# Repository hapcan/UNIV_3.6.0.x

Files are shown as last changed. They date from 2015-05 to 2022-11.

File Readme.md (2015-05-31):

UNIV 3.6.0.x
============

Light Dimmer - 1 channel trailing edge light dimmer 250W for DIN rail

Device webpage: http://hapcan.com/devices/universal/univ_3/univ_3-6-0-x/

Hardware designed in Eagle PCB Software http://www.cadsoftusa.com/

Firmware created in Microchip MPLAB http://www.microchip.com/mplabide/ in assembly language

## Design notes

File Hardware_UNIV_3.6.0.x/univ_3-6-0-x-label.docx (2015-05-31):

DIMMER RC

| | UN = 230V AC 50Hz
| | PMAX = 250W
| | PMAX = 50W
TYPE | UNIV 3.6.0.x
S/N | 000007A6h

hapcan.com

ŚCIEMNIACZ RC

| | UN = 230V AC 50Hz
| | PMAX = 250W
| | PMAX = 50W
TYP | UNIV 3.6.0.x
S/N | 000007A6h

hapcan.com

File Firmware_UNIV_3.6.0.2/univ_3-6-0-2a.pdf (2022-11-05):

## DIMMER FIRMWARE

# UNIV 3.6.0.2

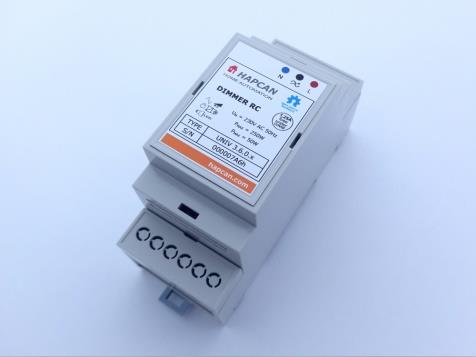
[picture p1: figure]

© 2019 hapcan.com | univ_3-6-0-2a.pdf - page 1 / 7

### 1. Features

- Firmware for light dimmer
- Voltage control in 256 steps (0-255)
- 4 defined dimmer characteristics
- Possibility to program user defined characteristic
- Adjustable minimum and maximum values
- Last state memory
- Adjustable dimming time for each channel
- 10 control instructions
- 3 blocking instructions
- 1 timer for instruction execution delay 1s-24h
- Allows defining up to 128 CAN messages which can indirectly control the module
- Settable power up states
- Uptime counter
- Health check monitor
- Transmit (42 messages) and receive (42 messages) FIFO buffers New:
- Operators <-small or equal and> greater than or equal were added to support boxes
- The flash of the light source that occurred when the set dimmer value was saved to the eeprom memory has been eliminated

### 2. Compatibility

- Firmware is compatible to previous UNIV 3.6.0.1
- Firmware for UNIV 3.6.0.x module
- Firmware can be uploaded into processor with bootloader version 3.1 or compatible.

### 3. Firmware version

UNIV | 3 | . | 6 | . | 0 | . | 2
firmware version
application version
application type (dimmer)
processor version
universal processor

### 4. Communication Frames (messages)

### 4.1. Dimmer message

The module sends message to the bus, when the dimmer state changes.

Table 1. Dimmer frame (0x306)
Frame type | Flags | Module | Group | D0 | D1 | D2 | D3 | D4 | D5 | D6 | D7
0x306 | 3 | 2 | 1 | 0 | Node Nr | Group Nr | 0xFF | 0xFF | CHANNEL | STATUS | 0xFF | INSTR1 | INSTR2 | TIMER
0x306 | – dimmer frame
3 | - | - not used flag, read as “0”
2 | - | - not used flag, read as “0”
1 | - | - not used flag, read as “0”
0 | RE | - response flag, flag is equal “1” if node was requested. If flag is equal „0” it means that status of output has just changed.
Node Nr | - message sender node number
Group Nr | - message sender group number
CHANNEL | - output channel (always 0x01 in this device)
STATUS | - current status of output 0x00 – 0xFF
INSTR1 | - instruction that is waiting for execution, or 0xFF if none instruction
INSTR2 | - second byte of instruction that is waiting for execution, or 0xFF
TIMER | - delay value of waiting instruction, or 0x00 if none waiting

Table 2. Dimmer error frame
The module sends message to the bus, when the dimmer error changes.
Frame type | Flags | Module | Group | D0 | D1 | D2 | D3 | D4 | D5 | D6 | D7
0x306 | 0x0 | Node Nr | Group Nr | 0xFF | 0xFF | 0xF0 | ERROR | 0xFF | 0xFF | 0xFF | 0xFF
0xF0 | - error frame
ERROR | 0x00 – <00000000> - no error 0x01 – <00000001> (bit 0) – 230V mains problem 0x02 – <00000010> (bit 1) - overheating

Table 3. Dimmer transistor conduction time
The frame is sent only in response to STATUS REQUEST
Frame type | Flags | Module | Group | D0 | D1 | D2 | D3 | D4 | D5 | D6 | D7
0x306 | 0x1 | Node Nr | Group Nr | 0xFF | 0xFF | 0xFE | COND1 | COND0 | 0xFF | 0xFF | 0xFF
0xFE | MOSFET - transistor conduction time frame
COND | - COND1*256 + COND0 – transistor conduction time frame in mains half sine wave (in microseconds)

Table 4. Mains frequency frame
The frame is sent only in response to STATUS REQUEST
Frame type | Flags | Module | Group | D0 | D1 | D2 | D3 | D4 | D5 | D6 | D7
0x306 | 0x1 | Node Nr | Group Nr | 0xFF | 0xFF | 0xFF | FREQ1 | FREQ0 | 0xFF | 0xFF | 0xFF
0xFF | - mains frequency frame
FREQ | - FREQ1*256 + FREQ0 – mains sine wave half period time (value in microseconds)

### 4.2. Status request

Status of module can be checked by sending from computer STATUS REQUEST frame (0x109) (Table 5).

Table 5. STATUS REQUEST frame (0x109).
Frame type | Flags | Module | Group | D0 | D1 | D2 | D3 | D4 | D5 | D6 | D7
0x109 | 0x0 | COMP ID1 | COMP ID2 | 0xXX | 0xXX | Node Nr | Group Nr | 0xXX | 0xXX | 0xXX | 0xXX
0x1090 | – STATUS REQUEST frame
COMP ID1 | - computer identifier (must be unique on the network)
COMP ID2 | - computer identifier (must be unique on the network)
Node Nr | - node number of requested module
Group Nr | - group number of requested module
0xXX | - inessential data

As response the module will send dimmer frames. The meaning of bytes is the same as in Table 1,2,3,4.

Table 6. Response to STATUS REQUEST
Frame type | Flags | Module | Group | D0 | D1 | D2 | D3 | D4 | D5 | D6 | D7
0x306 | 0x1 | Node Nr | Group Nr | 0xFF | 0xFF | CHANNEL | STATUS | 0xFF | INSTR1 | INSTR2 | TIMER
Frame type | Flags | Module | Group | D0 | D1 | D2 | D3 | D4 | D5 | D6 | D7
0x306 | 0x1 | Node Nr | Group Nr | 0xFF | 0xFF | 0xF0 | ERROR | 0xFF | 0xFF | 0xFF | 0xFF
Frame type | Flags | Module | Group | D0 | D1 | D2 | D3 | D4 | D5 | D6 | D7
0x306 | 0x1 | Node Nr | Group Nr | 0xFF | 0xFF | 0xFE | COND1 | COND0 | 0xFF | 0xFF | 0xFF
Frame type | Flags | Module | Group | D0 | D1 | D2 | D3 | D4 | D5 | D6 | D7
0x306 | 0x1 | Node Nr | Group Nr | 0xFF | 0xFF | 0xFF | FREQ1 | FREQ0 | 0xFF | 0xFF | 0xFF

### 4.3. Uptime request

Table 7. UPTIME REQUEST (0x113).
Frame type | Flags | Module | Group | D0 | D1 | D2 | D3 | D4 | D5 | D6 | D7
0x113 | 0x0 | COMP ID1 | COMP ID2 | 0xXX | 0xXX | Node Nr | Group Nr | 0xXX | 0xXX | 0xXX | 0xXX
0x1130 | – UPTIME REQUEST frame
COMP ID1 | - computer identifier (must be unique on the network)
COMP ID2 | - computer identifier (must be unique on the network)
Node Nr | - node number of requested module
Group Nr | - group number of requested module
0xXX | - inessential data

Table 8. Response to UPTIME REQUEST (0x113).
Frame type | Flags | Module | Group | D0 | D1 | D2 | D3 | D4 | D5 | D6 | D7
0x113 | 0x1 | Node Nr | Group Nr | 0xFF | 0xFF | 0xFF | 0xFF | UPTIME3 | UPTIME2 | UPTIME1 | UPTIME0
0x1131 | – Response to UPTIME REQUEST frame
Node Nr | - node number on the network
Group Nr | - group number of the node on the network
UPTIME | - (UPTIME3*256³+UPTIME2*256²+UPTIME1*256¹+UPTIME3*256⁰
) in seconds

### 4.4. Health check request

Table 9. HEALTH CHECK - STATUS REQUEST (0x115).
Frame type | Flags | Module | Group | D0 | D1 | D2 | D3 | D4 | D5 | D6 | D7
0x115 | 0x0 | COMP ID1 | COMP ID2 | 0x01 | 0xXX | Node Nr | Group Nr | 0xXX | 0xXX | 0xXX | 0xXX
0x1150 | – HEALTH CHECK REQUEST frame
COMP ID1 | - computer identifier (must be unique on the network)
COMP ID2 | - computer identifier (must be unique on the network)
0x01 | - status request
Node Nr | - node number of requested module
Group Nr | - group number of requested module
0xXX | - inessential data

As response the module will send two frames (Table 10).

Table 10. Response to HEALTH CHECK - STATUS REQUEST (0x115).
Frame type | Flags | Module | Group | D0 | D1 | D2 | D3 | D4 | D5 | D6 | D7
0x115 | 0x1 | Node Nr | Group Nr | 0x01 | RXCNT | TXCNT | RXCNTMX | TXCNTMX | CANINTCNT | RXERRCNT | TXERRCNT
0x1151 | – Response to HEALTH CHECK REQUEST frame
Node Nr | - node number on the network
Group Nr | - group number of the node on the network
0x01 | - frame 1 (current values)
RXCNT | - current level of receive FIFO buffer
TXCNT | - current level of transmit FIFO buffer
RXCNTMX | - maximum level of receive FIFO buffer since power up
TXCNTMX | - maximum level of transmit FIFO buffer since power up
CANINTCNT | - number of CAN interface restarts since power up
RXERRCNT | - current receive errors register
TXERRCNT | - current transmit errors register
Frame type | Flags | Module | Group | D0 | D1 | D2 | D3 | D4 | D5 | D6 | D7
0x115 | 0x1 | Node Nr | Group Nr | 0x02 | 0xFF | 0xFF | RXCNTMXE | TXCNTMXE | CANINTCNTE | RXERRCNTE | TXERRCNTE
0x1151 | – Response to HEALTH CHECK REQUEST frame
Node Nr | - node number on the network
Group Nr | - group number of the node on the network
0x02 | - frame 2 (maximum values saved in eeprom memory)
RXCNTMXE | - maximum ever level of receive FIFO buffer
TXCNTMXE | - maximum ever level of transmit FIFO buffer
CANINTCNTE | - maximum ever number of CAN interface restarts
RXERRCNTE | - maximum ever receive errors
TXERRCNTE | - maximum ever transmit errors

To clear maximum values saved in eeprom memory the frame shown in Table 11 must be sent. There is no response to this message.

Table 11. HEALTH CHECK - CLEAR REQUEST (0x115).
Frame type | Flags | Module | Group | D0 | D1 | D2 | D3 | D4 | D5 | D6 | D7
0x115 | 0x0 | COMP ID1 | COMP ID2 | 0x02 | 0xXX | Node Nr | Group Nr | 0xXX | 0xXX | 0xXX | 0xXX
0x1150 | – HEALTH CHECK REQUEST frame
COMP ID1 | - computer identifier (must be unique on the network)
COMP ID2 | - computer identifier (must be unique on the network)
0x02 | - clear request
Node Nr | - node number of requested module
Group Nr | - group number of requested module
0xXX | - inessential data

### 5. Module control

The module can be controlled directly from PC, or indirectly by other modules.

### 5.1. Control instruction

The table below shows all instructions, which can be executed by the module. Some of them can be executed only with direct control and other with indirect control (through other modules).

Table 12. Module control instructions

Instruction | Instruction Codding | Note | Control
INSTR1 | INSTR2 | INSTR3 | INSTR4 | INSTR5 | INSTR6 | INSTR7 | INSTR8
SET TO… | 0x00 | STATE | TIMER | 0xXX | 0xXX | 0xXX | 0xXX | 0xXX | Sets the state of the dimmer immediately at the level specified by the byte STATE (0-255). The SOFT START feature takes 1s to turn device on and off. Instructions may be delayed if the TIMER is not zero. | √ | √
TOGGLE | 0x01 | 0xXX | TIMER | 0xXX | 0xXX | 0xXX | 0xXX | 0xXX | If dimmer is on, it will be turned off. If it is off, it will be turned to the maximum or the last memorized value (if state memory is set in the configuration). Instructions may be delayed if the TIMER is not zero. | √ | √
STEP DOWN BY … | 0x02 | VALUE | TIMER | 0xXX | 0xXX | 0xXX | 0xXX | 0xXX | Dimmer state will be reduced by the value indicated in the VALUE byte. | √ | √
STEP UP BY … | 0x03 | VALUE | TIMER | 0xXX | 0xXX | 0xXX | 0xXX | 0xXX | Dimmer state will be increased by the value indicated in the VALUE byte. | √ | √
STOP | 0x04 | 0xXX | 0xXX | 0xXX | 0xXX | 0xXX | 0xXX | 0xXX | It stops instruction which is being executed eg. START or SET SOFTLY TO ... | √ | √
START | 0x05 | 0xXX | 0xXX | 0xXX | 0xXX | 0xXX | 0xXX | 0xXX | Instruction START begins typical control process. If within 400ms from START instruction, controller receives STOP instruction then it toggles channel’s state (exactly the same as TOGGLE instruction). If after that time instruction STOP is not received then dimmer is brightened (if previous state was min or 0), or channel is dimmed (if previous state was max). It gives possibility to control with one button. If button is pressed for less than 400ms the dimmer will turn on or off. If button is pressed for longer than 400ms, then dimmer will dim or brighten. | √ | √
SET SOFTLY TO… | 0x06 | STATE | TIMER | 0xXX | 0xXX | 0xXX | 0xXX | 0xXX | Sets the dimmer statel slowly to the level specified by the byte STATE (0-255). Instructions may be delayed if the TIMER is not zero. | √ | √
SET MINIMUM TO… | 0x07 | VALUE | 0xXX | 0xXX | 0xXX | 0xXX | 0xXX | 0xXX | Sets dimmer minimum value. Byte VALUE (0-255). | √ | √
SET MAXIMUM TO … | 0x08 | VALUE | 0xXX | 0xXX | 0xXX | 0xXX | 0xXX | 0xXX | Sets dimmer maximum value. Byte VALUE (0-255). | √ | √
SET DIMMING SPEED TO … | 0x09 | VALUE | 0xXX | 0xXX | 0xXX | 0xXX | 0xXX | 0xXX | It sets dimming time. VALUE byte (0-255) defines time when dimmer changes its state from 0 to 255. This byte can hold value from 0 – 255 which corresponds to 1s – 256s. | √ | √
ENABLE BOX | 0xDD | BoxX | BoxY | 0xXX | 0xXX | 0xXX | 0xXX | 0xXX | It enables chosen boxes – these boxes will be compared with next received message from the bus. | | √
DISABLE BOX | 0xDE | BoxX | BoxY | 0xXX | 0xXX | 0xXX | 0xXX | 0xXX | It disables chosen boxes – these boxes will be passed when next message arrives from the bus. | | √
TOGGLE BOX | 0xDF | BoxX | BoxY | 0xXX | 0xXX | 0xXX | 0xXX | 0xXX | It toggles boxes – enables when they are disabled and vice versa | | √

Direct

Indirect

0xXX – inessential data

BoxX | Note
0x00 | - from Box 1
0x01 | - from Box 2
…
0x7F | - from Box 128
BoxY | Note
0x00 | + 0 -(and not anyone else)
0x01 | + 1 -( and 1 following)
…
0x7F | +127 -( and 127 following)

### 5.2. Timer

Each channel has its own timer which can delay execution of the instruction. Delay can be chosen between 1s-24h set in TIMER register. Drawing below shows delay dependence of TIMER register.

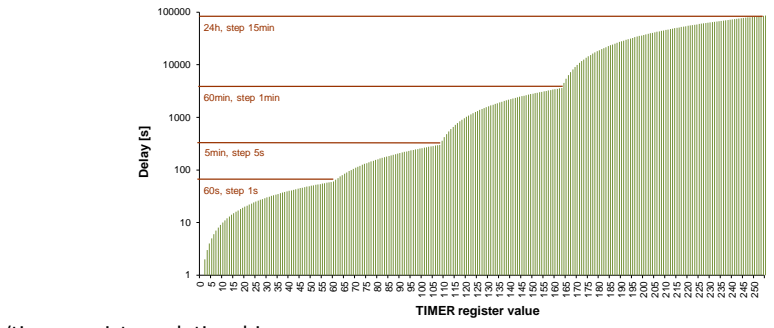
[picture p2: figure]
Delay [s]; TIMER register value; 60s, step 1s; 5min, step 5s; 60min, step 1min; 24h, step 15min

Figure 1. Delay/timer register relationship

### 5.3. Direct control

It is possible to control module by sending DIRECT CONTROL message. The message contains instruction, which will be executed by the module.

Table 13. DIRECT CONTROL frame (0x10A).
Frame type | Flags | Module | Group | D0 | D1 | D2 | D3 | D4 | D5 | D6 | D7
0x10A | 0x0 | COMP ID1 | COMP ID2 | INSTR1 | INSTR2 | Node Nr | Group Nr | INSTR3 | INSTR4 | INSTR5 | INSTR6
0x10A | – DIRECT CONTROL frame
COMP ID1 | - computer identifier (must be unique on the network)
COMP ID2 | - computer identifier (must be unique on the network)
Node Nr | - node number of requested module
Group Nr | - group number of requested module
INSTR1-6 | - instruction to be executed (byte1)

### 5.4. Indirect control

Indirect control means that module will react to messages sent by other modules on the network. It depends on configuration programmed into the module boxes (memory cells).
This firmware has feature to set simple conditions of executing instruction. To do so, you can use blocking instruction (0xDD – 0xDF) shown in Table 12.

### 6. Configuration

Parameters that can be configured with this firmware. Configuration process can be made using HAPCAN Programmer.

### 6.1. Module identifier

Every module on the network must have unique identifier. The identifier is made of two bytes, module number (1 byte) and group number (1 byte).

### 6.2. Module description

Every module can have 16 char description, which makes easier for user (programmer) to distinguish nodes.

### 6.3. Dimmer channel name

The only one channel of this device can be named with 32 chars.

### 6.4. Power up minimum and maximum values

It is possible to set minimum and maximum values.

### 6.5. Power up dimming speed

This parameter defines how fast dimmer goes from value 0 to value 255. The dimming speed can be chosen between 1s and 256s with 1s step.

### 6.6. Power up state

It is possible to configure dimmer state at startup after power loss. At startup values can be chosen between 0 and 255 or the or the last state saved in non-volatile memory can be taken. The last state value must be unchanged for at least 6s before power failure.

### 6.7. Last state memory

The dimmer last state can be remembered. In this mode, when channel is being switched on, it sets to the value that was before switching off. In no state memory mode it sets to the maximum value.

### 6.8. Dimmer characteristics

One of five dimmer characteristics can be chosen. For the light control is it advised to choose square or incandescent curve. Only few types of LED bulbs might require “LED” curve.

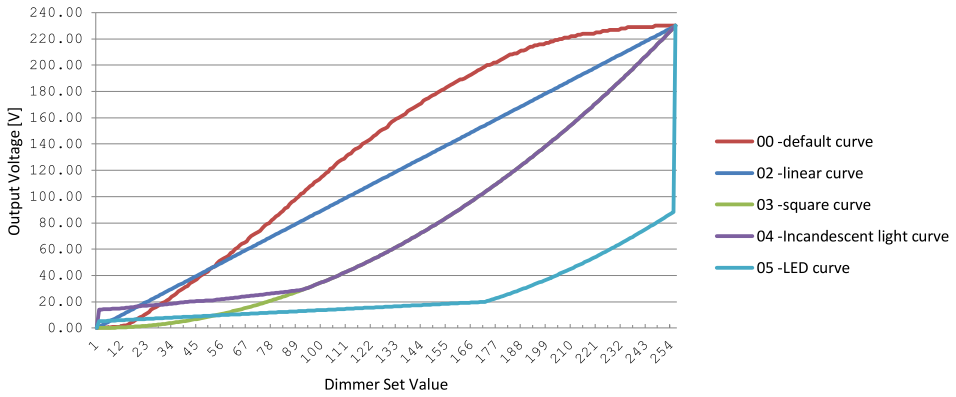
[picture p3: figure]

Figure 2. Defined dimmer characteristics.

### 6.9. User defined characteristic

When defining user characteristic it is required to set, for each dimmer value, the transistor conduction time in the half period of mains sine wave. This time must be contained within the range 0 - 9215 µs. Value equal or greater than 9215 µs means a continuous conduction of the transistor.

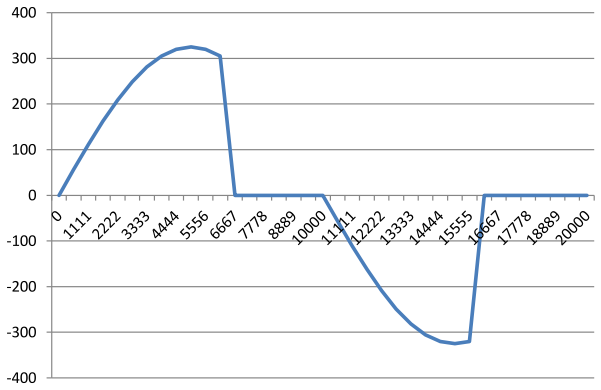
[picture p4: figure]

Figure 3. An example of the transistor conduction time equal 6667µs

6.10. Text notes.
Up to 1024 characters can be written into processor’s memory.

### 6.11. Linking devices

The indirect control is used to program the dependencies between modules. It is a controlling the module by messages sent from other modules. Each module when changing its status (eg when button is pressed or released in the button module) sends information that can be used to control the same module, as well as to control other modules located on the bus. For this purpose, the module has 128 boxes (memory cells) into which you can enter messages to which the module is to react when it receives them from the bus. Each box contains information about what message should initiate the action and what instruction should be made when this message is received.

In the figure on a side, the toggle instruction has been programmed, which changes the current state of the dimmer at the moment of receiving a message from the module button o ID (4.1) - see the description of the BUTTON FRAME in the document "Firmware note" of the button module.

The message bytes are saved in hexadecimal format.

Operators at the front of bytes indicate that the module will react to a message received from the bus in which this byte:
x - can have any value
= - is identical to byte entered here
! - is different than byte entered here
< - is less or equal to byte entered here
> - is greater or equal to byte entered here

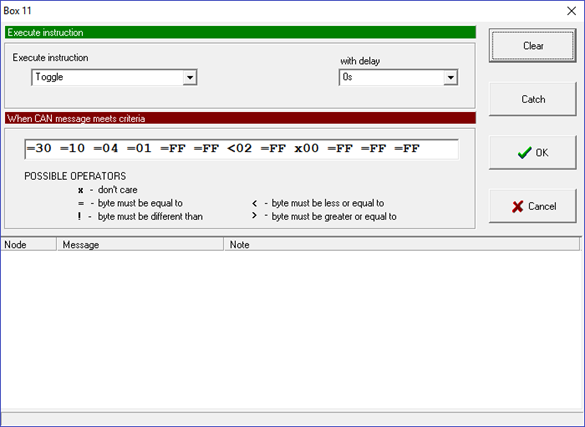
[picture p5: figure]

In this example:
=30 =10
=04 =01
=FF =FF
<02
=FF
x00

=FF =FF =FF

– button message
– module ID is (4,1)
– these bytes are not used and in button frame are always 0xFF
– button number is less or equal 2, means button number 1 or 2
– button is pressed
– it is a byte which gives LED status in the button module. Because we don’t want to make instruction execution to be depended on this byte, so this byte can have any value.
– these bytes are not used and in button frame are always 0xFF

As a result, the module will execute instructions when the module receives a message from the button with ID (4.1), when button number 1 or 2 has been pressed. Instruction is executed regardless of the LED status in the button module.

Each own and received from the bus message informing about the change of module status is checked with each active (enabled) box in the order from box no. 1 to 128. Therefore, you can set the reaction to the same message in two or more boxes. For example, in the first box instruction can be executed without delay, and in the next box another instruction can be executed after the defined time. It is important to keep the logical order of instruction executing to get the desired operation of the module. Calling an instruction that is to be executed without delay will cancel the previously set instruction with a delay.
Boxes can be dynamically activated (enabled) and deactivated (disabled). Blocking instructions 0xDD-0XDF are used for this (Table 12). In this way, you can control which boxes are to be checked after receiving the message.

### 7. License

HAPCAN Home Automation Project firmware, Copyright (C) 2019 hapcan.com

This program is free firmware: you can redistribute it and/or modify it under the terms of the GNU General Public License as published by the Free Software Foundation, either version 3 of the License, or (at your option) any later version.

This firmware is distributed in the hope that it will be useful, but WITHOUT ANY WARRANTY; without even the implied warranty of MERCHANTABILITY or FITNESS FOR A PARTICULAR PURPOSE. See the GNU General Public License for more details.

You should have received a copy of the GNU General Public License along with this firmware. If not, see http://www.gnu.org/licenses/gpl-3.0.html.

### 8. Document version

File | Note | Date
univ_3-6-0-2a.pdf | Original version | February 2019

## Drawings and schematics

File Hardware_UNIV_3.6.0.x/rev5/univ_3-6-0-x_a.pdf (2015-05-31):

## DIMMER RC

# UNIV 3.6.0.x

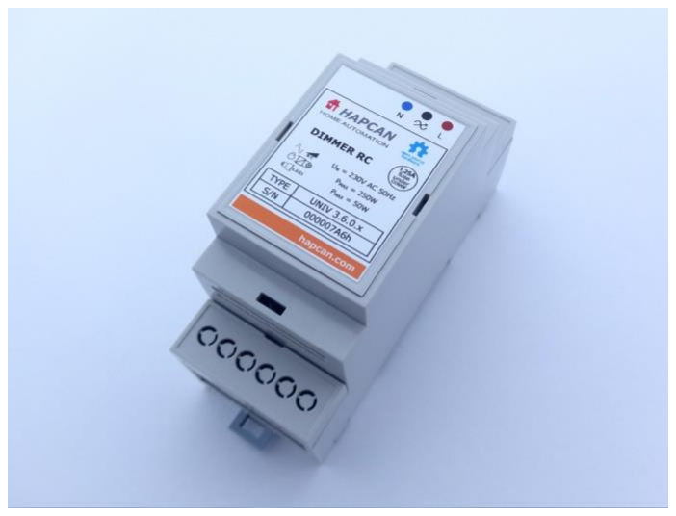
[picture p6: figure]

© 2015 hapcan.com | univ_3-6-0-x_a.pdf - page 1 / 6

### 1. Features

- Light dimmer for maximum load 250W
- - Phase controlled (trailing edge)
- - Suitable for resistive and capacitive loads:
- incandescent lamps (classic and halogen 230V) – maximum load 250W
- dimmable electronic transformers – maximum load 250W
- dimmable LED 230V lamps – maximum load 50W
- It has electronic thermal protection
- Blow fuse for overload and short-circuit protection
- Operation voltage 10-24V.
- Maximum current consumption from the bus 8mA.
- For DIN rail mounting.
- Dimensions 90x58x36 mm (2 mod)
- Operating of module depends on firmware uploaded into it.
- Schematic and PCB design can be downloaded from hapcan.com site

WARNING. MAINS VOLTAGES ARE ACCESSIBLE WHEN THE COVER IS REMOVED. ENSURE ANY EXTERNAL WIRING IS CARRIED OUT SAFELY. IN ANY DOUBT CONSULT A SUITABLY QUALIFIED PERSON. PLEASE TAKE CARE WITH MAINS ELECTRICITY.

### 2. Application version

UNIV | 3 | . | 6 | . | 0 | . | x
firmware version
application version
application type (dimmer)
processor version
universal processor

### 3. Technical data

Bus side
Parameter | Symbol | Value | Unit
Power supply voltage | US | 10-24V | V
Maximum current consumption | ISMAX | 8 | mA
Bus connector type | 2x RJ45 connectors

Load side
Parameter | Symbol | Value | Unit
Power supply voltage | UN | 230 | V AC
Power supply frequency | fN | 50 | Hz

Maximum load
Classical and halogen 230V lamps, low voltage lamps with electronic transformer | PLOAD | 250 | W
LED 230V lamps | | 50
Voltage regulating range | Uφ | 0 – UN | V
Standby power consumption | P0 | <1 | W
Quick acting fuse 5x20mm | | 1.25 | A
Connector type | Terminal block (solid cable 4mm² , stranded 2,5mm² )

R C

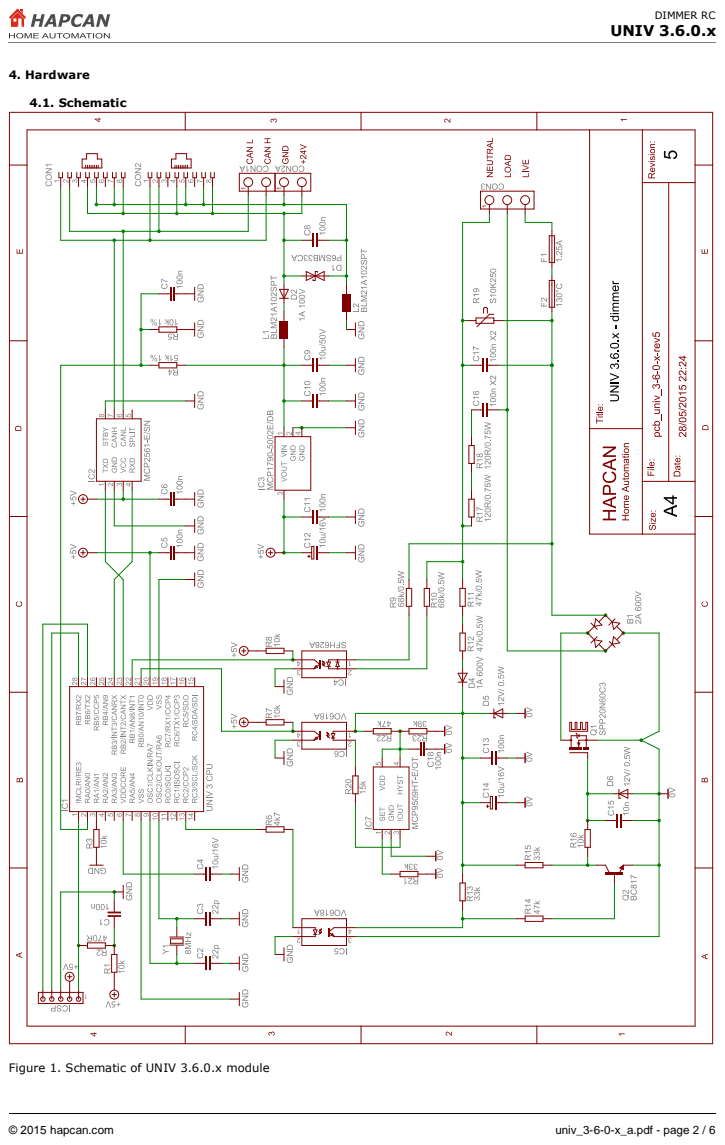
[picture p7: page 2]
4. Hardware; 4.1. Schematic

Figure 1. Schematic of UNIV 3.6.0.x module

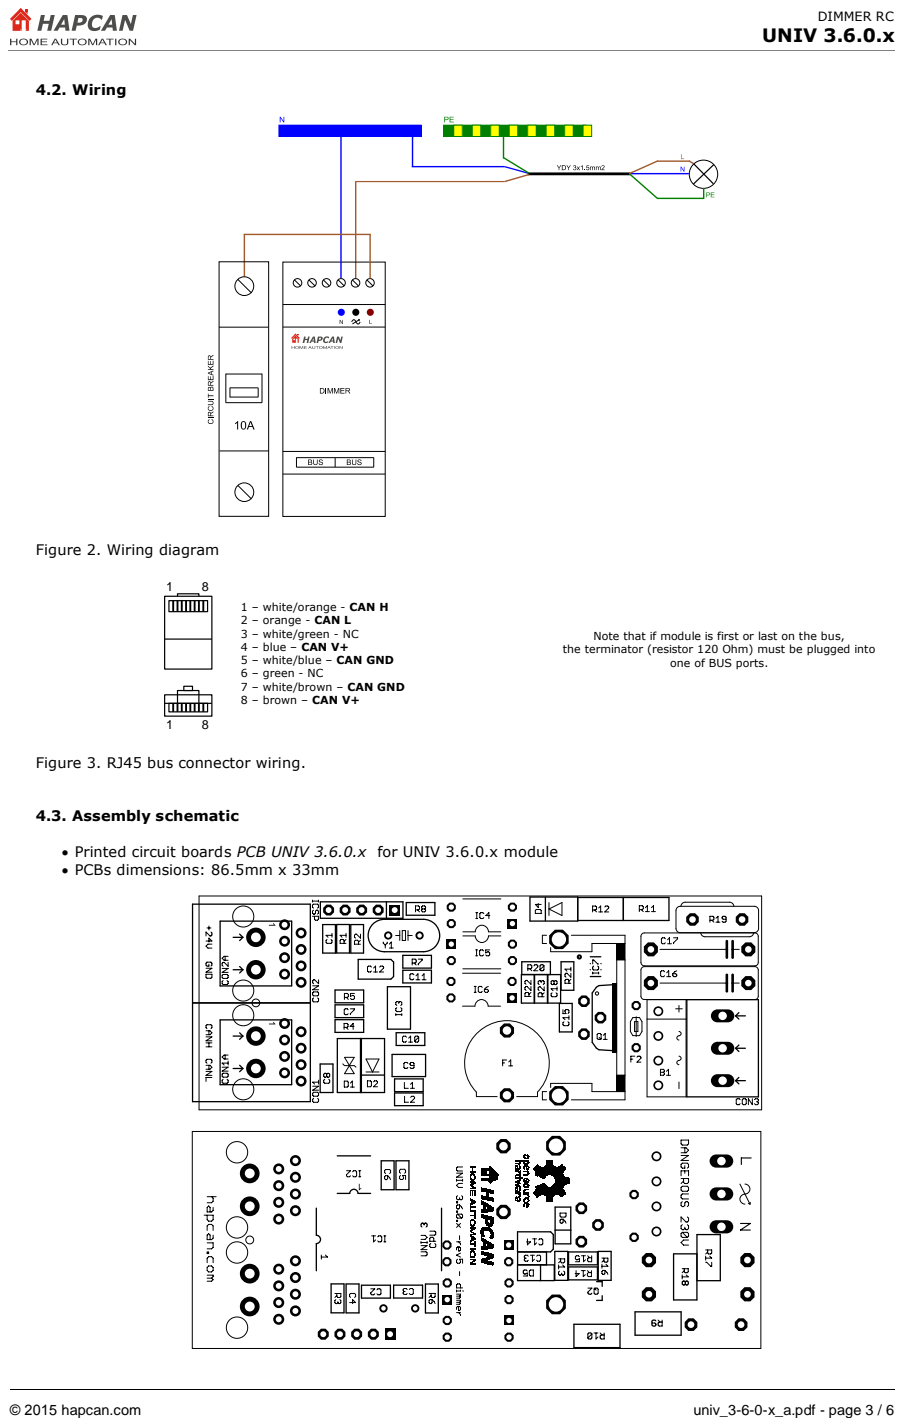
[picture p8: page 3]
4.2. Wiring; 4.3. Assembly schematic

Figure 2. Wiring diagram

1 – white/orange - CAN H
2 – orange - CAN L
3 – white/green - NC
4 – blue – CAN V+
5 – white/blue – CAN GND
6 – green - NC
7 – white/brown – CAN GND
8 – brown – CAN V+

Note that if module is first or last on the bus,
the terminator (resistor 120 Ohm) must be plugged into

one of BUS ports.

Figure 3. RJ45 bus connector wiring.

• Printed circuit boards PCB UNIV 3.6.0.x for UNIV 3.6.0.x module
• PCBs dimensions: 86.5mm x 33mm

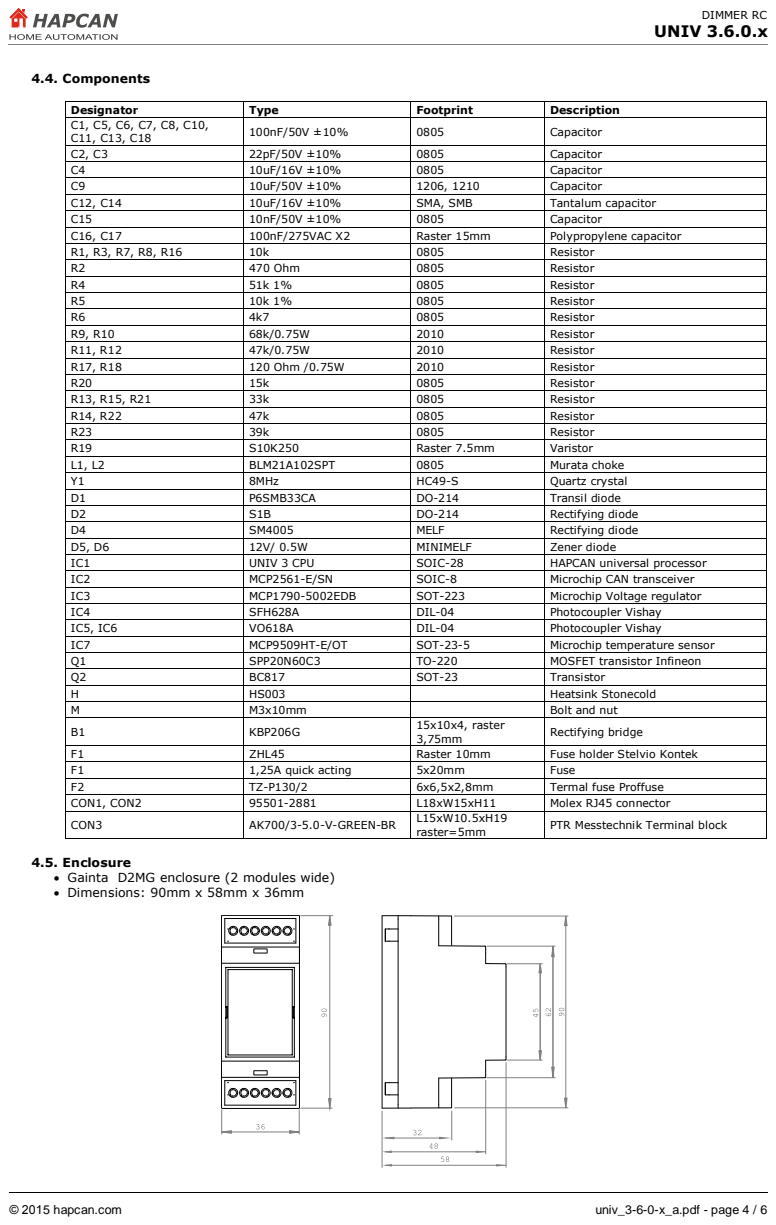
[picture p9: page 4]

Designator | Type | Footprint | Description
C1, C5, C6, C7, C8, C10, C11, C13, C18 | 100nF/50V ±10% | 0805 | Capacitor

C2, C3 | 22pF/50V ±10% | 0805 | Capacitor
C4 | 10uF/16V ±10% | 0805 | Capacitor
C9 | 10uF/50V ±10% | 1206, 1210 | Capacitor
C12, C14 | 10uF/16V ±10% | SMA, SMB | Tantalum capacitor
C15 | 10nF/50V ±10% | 0805 | Capacitor
C16, C17 | 100nF/275VAC X2 | Raster 15mm | Polypropylene capacitor
R1, R3, R7, R8, R16 | 10k | 0805 | Resistor
R2 | 470 Ohm | 0805 | Resistor
R4 | 51k 1% | 0805 | Resistor
R5 | 10k 1% | 0805 | Resistor
R6 | 4k7 | 0805 | Resistor
R9, R10 | 68k/0.75W | 2010 | Resistor
R11, R12 | 47k/0.75W | 2010 | Resistor
R17, R18 | 120 Ohm /0.75W | 2010 | Resistor
R20 | 15k | 0805 | Resistor
R13, R15, R21 | 33k | 0805 | Resistor
R14, R22 | 47k | 0805 | Resistor
R23 | 39k | 0805 | Resistor
R19 | S10K250 | Raster 7.5mm | Varistor
L1, L2 | BLM21A102SPT | 0805 | Murata choke
Y1 | 8MHz | HC49-S | Quartz crystal
D1 | P6SMB33CA | DO-214 | Transil diode
D2 | S1B | DO-214 | Rectifying diode
D4 | SM4005 | MELF | Rectifying diode
D5, D6 | 12V/ 0.5W | MINIMELF | Zener diode
IC1 | UNIV 3 CPU | SOIC-28 | HAPCAN universal processor
IC2 | MCP2561-E/SN | SOIC-8 | Microchip CAN transceiver
IC3 | MCP1790-5002EDB | SOT-223 | Microchip Voltage regulator
IC4 | SFH628A | DIL-04 | Photocoupler Vishay
IC5, IC6 | VO618A | DIL-04 | Photocoupler Vishay
IC7 | MCP9509HT-E/OT | SOT-23-5 | Microchip temperature sensor
Q1 | SPP20N60C3 | TO-220 | MOSFET transistor Infineon
Q2 | BC817 | SOT-23 | Transistor
H | HS003 | | Heatsink Stonecold
M | M3x10mm | | Bolt and nut
B1 | KBP206G | 15x10x4, raster 3,75mm | Rectifying bridge

F1 | ZHL45 | Raster 10mm | Fuse holder Stelvio Kontek
F1 | 1,25A quick acting | 5x20mm | Fuse
F2 | TZ-P130/2 | 6x6,5x2,8mm | Termal fuse Proffuse
CON1, CON2 | 95501-2881 | L18xW15xH11 | Molex RJ45 connector
CON3 | AK700/3-5.0-V-GREEN-BR | L15xW10.5xH19 raster=5mm | PTR Messtechnik Terminal block

4.5. Enclosure
• Gainta D2MG enclosure (2 modules wide)
• Dimensions: 90mm x 58mm x 36mm
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

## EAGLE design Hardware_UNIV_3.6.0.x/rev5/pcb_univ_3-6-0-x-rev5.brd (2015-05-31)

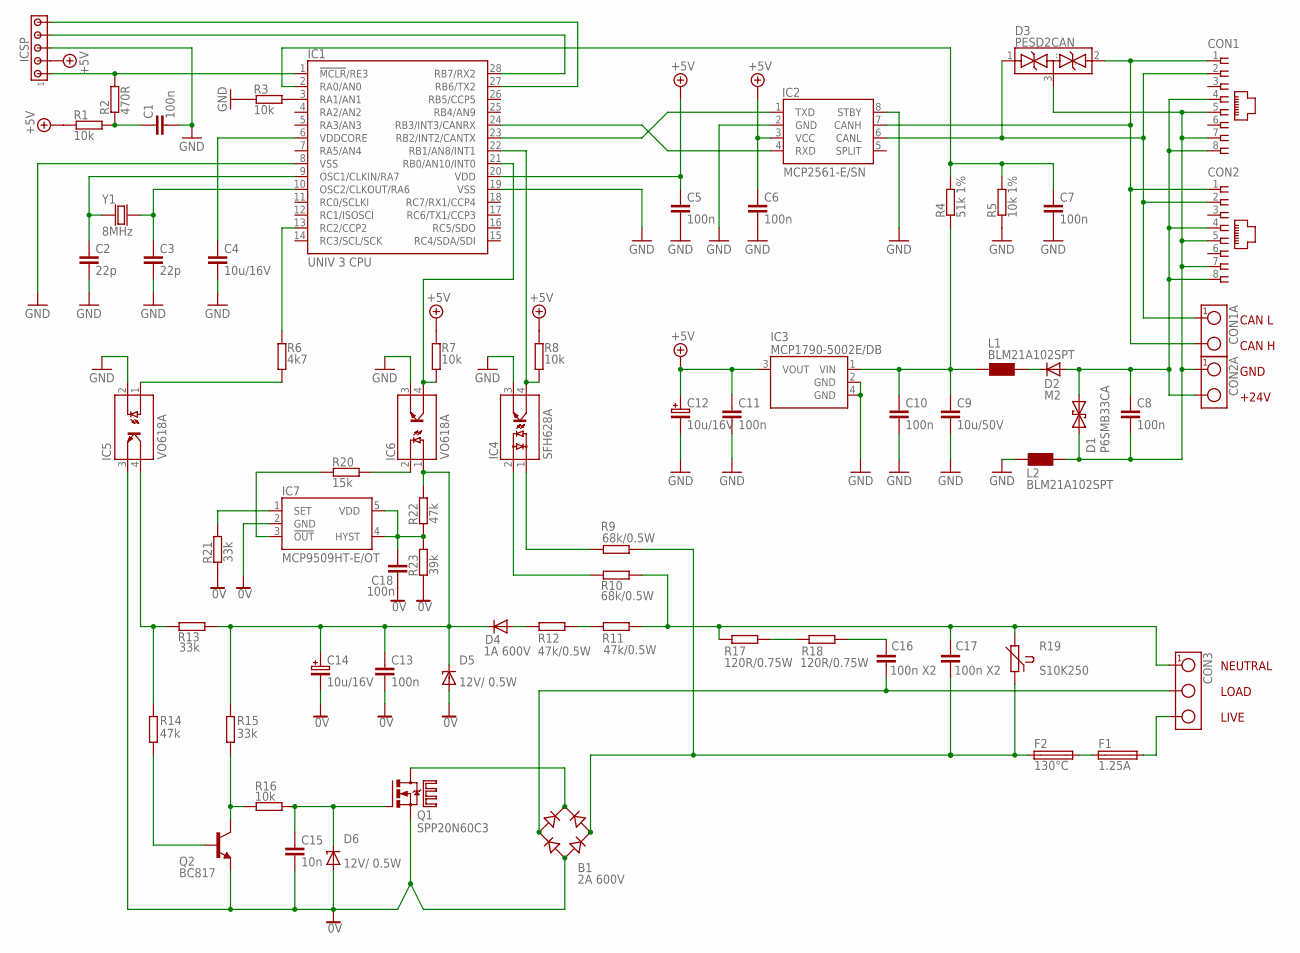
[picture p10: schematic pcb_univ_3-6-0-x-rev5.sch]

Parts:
B1: 2A 600V; RECTIFIER_KBP
C1, C5, C6, C7, C8, C10, C11, C13, C18: 100n; 0805
C2, C3: 22p; 0805
C4: 10u/16V; 0805
C9: 10u/50V; 1210
C12, C14: 10u/16V; SMC_B
C15: 10n; 0805
C16, C17: 100n X2; CAP-15X5
CON1, CON2: RJ45-SOCKET; RJ45-PCB-SOCKET
CON1A, CON2A: TERMINAL-2; ARK2-5X10,5MM
CON3: TERMINAL-3; ARK3-5X10.5MM
D1: P6SMB33CA; DO-214_TRANSIL2
D2: M2; DO-214
D3: PESD2CAN; SOT-23
D4: 1A 600V; DO-213
D5, D6: 12V/ 0.5W; SOD-80
F1: 1.25A; FUSE-HOLDER-V
F2: 130°C; FUSE-7.5
IC1: UNIV 3 CPU; UNIV3CPU
IC2: MCP2561-E/SN; SO-08
IC3: MCP1790-5002E/DB; SOT-223
IC4: SFH628A; DIL-04W
IC5, IC6: VO618A; DIL-04W
IC7: MCP9509HT-E/OT; SOT-23-5
ICSP: HEADER5; SIP-5
L1, L2: BLM21A102SPT; 0805
Q1: SPP20N60C3; TO220V-3
Q2: BC817; SOT-23
R1, R3, R7, R8, R16: 10k; 0805
R2: 470R; 0805
R4: 51k 1%; 0805
R5: 10k 1%; 0805
R6: 4k7; 0805
R9, R10: 68k/0.5W; 2010
R11, R12: 47k/0.5W; 2010
R13, R15, R21: 33k; 0805
R14, R22: 47k; 0805
R17, R18: 120R/0.75W; 2010
R19: S10K250; VARISTOR3
R20: 15k; 0805
R23: 39k; 0805
U$1: HEATSINK_HS003; HEATSINK_HS-003
Y1: 8MHz; CRYSTAL-HC49V

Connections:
0V: B1.-, C13.2, C14.- (2), C15.2, C18.2, D5.A, D6.A, IC5.3 (E), IC7.2 (GND), Q1.3 (S), Q2.2 (E), R21.2, R23.2
+5V: C5.1, C6.1, C11.1, C12.+ (1), IC1.20 (VDD), IC2.3 (VCC), IC3.3 (VOUT), ICSP.2, R1.1, R7.2, R8.2
GND: C1.2, C2.2, C3.2, C4.2, C5.2, C6.2, C7.2, C9.2, C10.2, C11.2, C12.- (2), IC1.8 (VSS), IC1.19 (VSS), IC2.2 (GND), IC2.8 (STBY), IC3.2 (GND), IC3.4 (GND), IC4.3 (E1), IC5.2 (K), IC6.3 (E), ICSP.3, L2.1, R3.1, R5.1
unnamed: C13.1, C14.+ (1), D4.C, D5.C, IC6.1 (A), R13.2, R15.1, R22.2
unnamed: IC1.24 (RB3/INT3/CANRX), IC2.4 (RXD)
unnamed: IC1.23 (RB2/INT2/CANTX), IC2.1 (TXD)
unnamed: CON1.1, CON1A.2, CON2.1, D3.2 (..), IC2.7 (CANH)
unnamed: IC4.2 (A2), R10.1
unnamed: B1.+, Q1.2 (D)
unnamed: C1.1, R1.2, R2.1
unnamed: IC1.1 (!MCLR!/RE3), ICSP.1, R2.2
unnamed: C8.1, CON1.4, CON1.8, CON2.4, CON2.8, CON2A.2, D1.C (2), D2.A
unnamed: IC1.28 (RB7/RX2), ICSP.4
unnamed: Q2.3 (C), R15.2, R16.2
unnamed: IC1.3 (RA1/AN1), R3.2
unnamed: B1.AC2, C17.2, F2.1, R9.2, R19.1
unnamed: IC1.27 (RB6/TX2), ICSP.5
unnamed: C3.1, IC1.10 (OSC2/CLKOUT/RA6), Y1.2
unnamed: C7.1, IC1.2 (RA0/AN0), R4.2, R5.2
unnamed: C9.1, C10.1, IC3.1 (VIN), L1.1, R4.1
unnamed: C15.1, D6.C, Q1.1 (G), R16.1
unnamed: IC1.13 (RC2/CCP2), R6.1
unnamed: B1.AC1, C16.1, CON3.2
unnamed: R11.2, R12.1
unnamed: CON3.3, F1.1
unnamed: IC4.1 (A1), R9.1
unnamed: F1.2, F2.2
unnamed: D4.A, R12.2
unnamed: R17.1, R18.2
unnamed: CON1.2, CON1A.1, CON2.2, D3.1 (.), IC2.6 (CANL)
unnamed: C17.1, CON3.1, R10.2, R11.1, R17.2, R19.2
unnamed: C16.2, R18.1
unnamed: IC5.4 (C), R13.1, R14.1
unnamed: Q2.1 (B), R14.2
unnamed: C8.2, CON1.5, CON1.7, CON2.5, CON2.7, CON2A.1, D1.A (1), D3.3 (...), L2.2
unnamed: IC1.21 (RB0/AN10/INT0), IC6.4 (C), R7.1
unnamed: IC7.3 (!OUT), R20.2
unnamed: IC7.1 (SET), R21.1
unnamed: IC1.22 (RB1/AN8/INT1), IC4.4 (C1), R8.1
unnamed: IC5.1 (A), R6.2
unnamed: C18.1, IC7.4 (HYST), IC7.5 (VDD), R22.1, R23.1
unnamed: C2.1, IC1.9 (OSC1/CLKIN/RA7), Y1.1
unnamed: IC6.2 (K), R20.1
unnamed: C4.1, IC1.6 (VDDCORE)
unnamed: D2.C, L1.2

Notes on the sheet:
LOAD
LIVE
NEUTRAL
CAN L
CAN H
GND
+24V

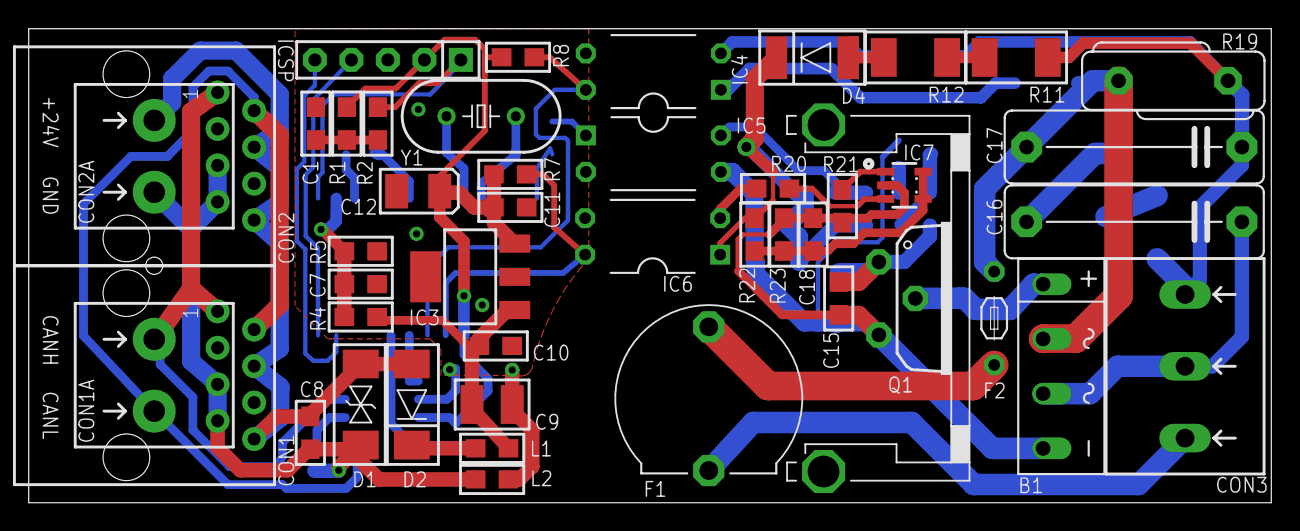
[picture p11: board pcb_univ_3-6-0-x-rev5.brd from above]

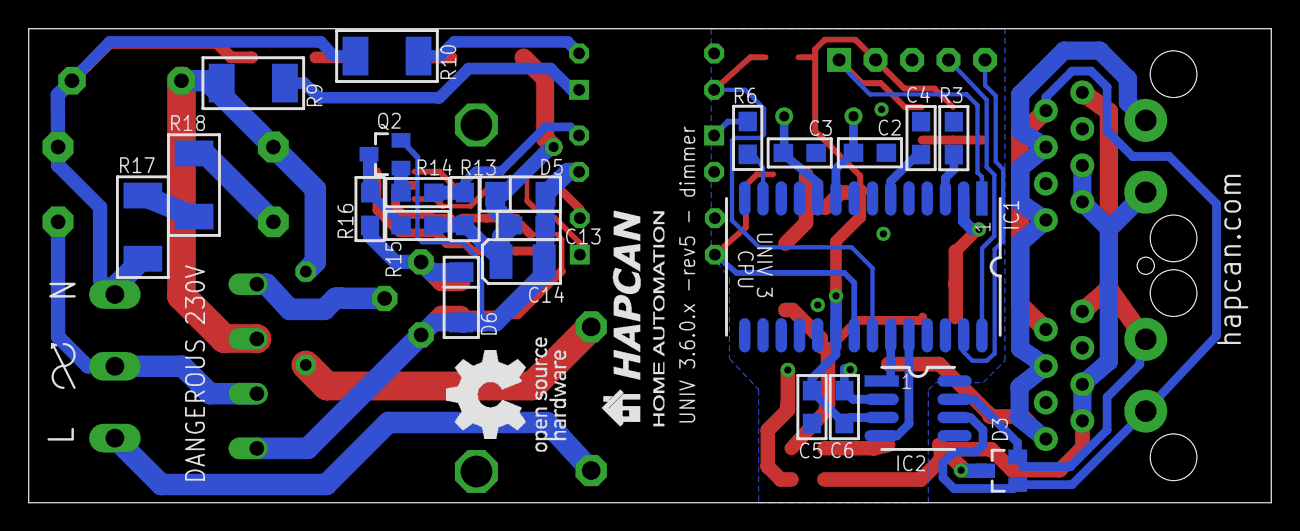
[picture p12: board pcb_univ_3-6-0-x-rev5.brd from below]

Board: 2 copper layers, 86.5 x 33.0 mm, 69 parts (23 on the bottom side), 45 nets.

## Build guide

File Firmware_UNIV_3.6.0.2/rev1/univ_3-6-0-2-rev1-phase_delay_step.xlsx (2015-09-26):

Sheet: dimming time
TIME reg | number of 20ms interrupts | number of steps on each 20ms | calculated PHASE step value (HEX) |  |  | final real PHASE delay
0 | 50 | 5.1 | 51999 | 334233 | 5.100068666 | 0.9999865363
1 | 100 | 2.55 | 28CCC | 167116 | 2.550026703 | 1.999979056
2 | 150 | 1.7 | 1B333 | 111411 | 1.700022889 | 2.999959609
3 | 200 | 1.275 | 14666 | 83558 | 1.275013352 | 3.999958113
4 | 250 | 1.02 | 1051E | 66846 | 1.020004578 | 4.99997756
5 | 300 | 0.85 | D999 | 55705 | 0.8500038148 | 5.999973072
6 | 350 | 0.7285714286 | BA83 | 47747 | 0.7285725185 | 6.999989528
7 | 400 | 0.6375 | A333 | 41779 | 0.6375066758 | 7.999916226
8 | 450 | 0.5666666667 | 9111 | 37137 | 0.5666742962 | 8.999878827
9 | 500 | 0.51 | 828F | 33423 | 0.5100022889 | 9.999955121
10 | 550 | 0.4636363636 | 76B0 | 30384 | 0.4636301213 | 11.0001481
11 | 600 | 0.425 | 6CCC | 27852 | 0.4249942779 | 12.00016157
12 | 650 | 0.3923076923 | 646E | 25710 | 0.392309453 | 12.99994166
13 | 700 | 0.3642857143 | 5D41 | 23873 | 0.3642786297 | 14.00027227
14 | 750 | 0.34 | 570A | 22282 | 0.3400015259 | 14.99993268
15 | 800 | 0.31875 | 5199 | 20889 | 0.3187457084 | 16.00021542
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

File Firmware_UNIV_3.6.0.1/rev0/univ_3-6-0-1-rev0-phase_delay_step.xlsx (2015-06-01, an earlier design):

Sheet: dimming time
TIME reg | number of 20ms interrupts | number of steps on each 20ms | calculated PHASE step value (HEX) |  |  | final real PHASE delay
0 | 50 | 5.1 | 51999 | 334233 | 5.100068666 | 0.9999865363
1 | 100 | 2.55 | 28CCC | 167116 | 2.550026703 | 1.999979056
2 | 150 | 1.7 | 1B333 | 111411 | 1.700022889 | 2.999959609
3 | 200 | 1.275 | 14666 | 83558 | 1.275013352 | 3.999958113
4 | 250 | 1.02 | 1051E | 66846 | 1.020004578 | 4.99997756
5 | 300 | 0.85 | D999 | 55705 | 0.8500038148 | 5.999973072
6 | 350 | 0.7285714286 | BA83 | 47747 | 0.7285725185 | 6.999989528
7 | 400 | 0.6375 | A333 | 41779 | 0.6375066758 | 7.999916226
8 | 450 | 0.5666666667 | 9111 | 37137 | 0.5666742962 | 8.999878827
9 | 500 | 0.51 | 828F | 33423 | 0.5100022889 | 9.999955121
10 | 550 | 0.4636363636 | 76B0 | 30384 | 0.4636301213 | 11.0001481
11 | 600 | 0.425 | 6CCC | 27852 | 0.4249942779 | 12.00016157
12 | 650 | 0.3923076923 | 646E | 25710 | 0.392309453 | 12.99994166
13 | 700 | 0.3642857143 | 5D41 | 23873 | 0.3642786297 | 14.00027227
14 | 750 | 0.34 | 570A | 22282 | 0.3400015259 | 14.99993268
15 | 800 | 0.31875 | 5199 | 20889 | 0.3187457084 | 16.00021542
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

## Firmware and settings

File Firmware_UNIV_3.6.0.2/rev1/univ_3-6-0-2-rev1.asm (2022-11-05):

;==============================================================================
;   MIT License
;
;   Copyright (c) 2022 HAPCAN Home Automation Project (http://hapcan.com)
;
;   Permission is hereby granted, free of charge, to any person obtaining a copy
;   of this software and associated documentation files (the "Software"), to deal
;   in the Software without restriction, including without limitation the rights
;   to use, copy, modify, merge, publish, distribute, sublicense, and/or sell
;   copies of the Software, and to permit persons to whom the Software is
;   furnished to do so, subject to the following conditions:
;
;   The above copyright notice and this permission notice shall be included in all
;   copies or substantial portions of the Software.
;
;   THE SOFTWARE IS PROVIDED "AS IS", WITHOUT WARRANTY OF ANY KIND, EXPRESS OR
;   IMPLIED, INCLUDING BUT NOT LIMITED TO THE WARRANTIES OF MERCHANTABILITY,
;   FITNESS FOR A PARTICULAR PURPOSE AND NONINFRINGEMENT. IN NO EVENT SHALL THE
;   AUTHORS OR COPYRIGHT HOLDERS BE LIABLE FOR ANY CLAIM, DAMAGES OR OTHER
;   LIABILITY, WHETHER IN AN ACTION OF CONTRACT, TORT OR OTHERWISE, ARISING FROM,
;   OUT OF OR IN CONNECTION WITH THE SOFTWARE OR THE USE OR OTHER DEALINGS IN THE
;   SOFTWARE.
;==============================================================================
;   Filename:              univ_3-6-0-2.asm
;   Associated diagram:    univ_3-6-0-x.sch
;   Author:                Jacek Siwilo
;   Note:                  Trailing edge dimmer for resistive and capacitive
;                          loads
;==============================================================================
;   Revision History
;   Rev:  Date:     Details:
;	0	  01.2019	Updated with "univ3-routines-rev8.inc",
;					save to eeprom blink eliminated
;	1	  11.2022	Updated with "univ3-routines-rev9.inc",
;==============================================================================
;===  FIRMWARE DEFINITIONS  ===================================================
;==============================================================================
    #define    ATYPE    .6                            ;application type [0-255]
    #define    AVERS    .0                         ;application version [0-255]
    #define    FVERS    .2                            ;firmware version [0-255]

    #define    FREV     .1                         ;firmware revision [0-65536]
;==============================================================================
;===  NEEDED FILES  ===========================================================
;==============================================================================
    LIST P=18F26K80                              ;directive to define processor
    #include <P18F26K80.INC>           ;processor specific variable definitions
    #include "univ_3-6-0-2-rev1.inc"                         ;project variables
INCLUDEDFILES   code
    #include "univ3-routines-rev9.inc"                     ;UNIV 3 CPU routines

;==============================================================================
;===  FIRMWARE CHECKSUM  ======================================================
;==============================================================================
FIRMCHKSM   code    0x001000
    DB      0x5E, 0xD7, 0x48, 0xFF, 0xFF, 0xFF, 0xFF, 0xFF
;==============================================================================
;===  FIRMWARE ID  ============================================================
;==============================================================================
FIRMID      code    0x001010
    DB      0x30, 0x00, 0x03,ATYPE,AVERS,FVERS,FREV>>8,FREV
;            |     |     |     |     |     |     |_____|_____ firmware revision
;            |     |     |     |     |     |__________________ firmware version
;            |     |     |     |     |_____________________ application version
;            |     |     |     |______________________________ application type
;            |     |     |________________________________ hardware version '3'
;            |_____|______________________________________ hardware type 'UNIV'
;==============================================================================
;===  MOVED VECTORS  ==========================================================
;==============================================================================
;PROGRAM RESET VECTOR
FIRMRESET   code    0x1020
        goto    Main
;PROGRAM HIGH PRIORITY INTERRUPT VECTOR
FIRMHIGHINT code    0x1030
        call    HighInterrupt
        retfie
;PROGRAM LOW PRIORITY INTERRUPT VECTOR
FIRMLOWINT  code    0x1040
        call    LowInterrupt
        retfie

;==============================================================================
;===  FIRMWARE STARTS  ========================================================
;==============================================================================
FIRMSTART   code    0x001050
;------------------------------------------------------------------------------
;---  LOW PRIORITY INTERRUPT  -------------------------------------------------
;------------------------------------------------------------------------------
LowInterrupt
        movff   STATUS,STATUS_LOW           ;save STATUS register
        movff   WREG,WREG_LOW               ;save working register
        movff   BSR,BSR_LOW                 ;save BSR register
        movff   FSR0L,FSR0L_LOW             ;save other registers used in low int
        movff   FSR0H,FSR0H_LOW
        movff   FSR1L,FSR1L_LOW
        movff   FSR1H,FSR1H_LOW

    ;main firmware ready flag
        banksel FIRMREADY
        btfss   FIRMREADY,0
        bra     ExitLowInterrupt            ;main firmware is not ready yet
    ;CAN buffer
        banksel CANFULL
        btfsc   CANFULL,0                   ;check if CAN received anything
        call    CANInterrupt                ;proceed with CAN interrupt

ExitLowInterrupt
        movff   BSR_LOW,BSR                 ;restore BSR register
        movff   WREG_LOW,WREG               ;restore working register
        movff   STATUS_LOW,STATUS           ;restore STATUS register
        movff   FSR0L_LOW,FSR0L             ;restore other registers used in low int
        movff   FSR0H_LOW,FSR0H
        movff   FSR1L_LOW,FSR1L
        movff   FSR1H_LOW,FSR1H
    return
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

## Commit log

2015-05-31 hardware UNIV 3.6.0.x rev5
    [pcb_univ_3-6-0-x-rev5.brd, pcb_univ_3-6-0-x-rev5.sch]
2015-06-01 firmware UNIV 3.6.0.1 rev0
    [univ_3-6-0-1-rev0-memory.xlsx, univ_3-6-0-1-rev0-phase_delay_step.xlsx]
2015-09-26 firmware UNIV 3.6.0.1 rev1
    [univ_3-6-0-1-rev1-memory.xlsx, univ_3-6-0-1-rev1-phase_delay_step.xlsx]
2019-02-10 firmware UNIV 3.6.0.2 rev0
    [univ_3-6-0-2-rev0-memory.xlsx, univ_3-6-0-2-rev0-phase_delay_step.xlsx]
2022-11-05 firmware UNIV 3.6.0.2 revision 1
    [univ_3-6-0-2-rev1-memory.xlsx, univ_3-6-0-2-rev1-phase_delay_step.xlsx]

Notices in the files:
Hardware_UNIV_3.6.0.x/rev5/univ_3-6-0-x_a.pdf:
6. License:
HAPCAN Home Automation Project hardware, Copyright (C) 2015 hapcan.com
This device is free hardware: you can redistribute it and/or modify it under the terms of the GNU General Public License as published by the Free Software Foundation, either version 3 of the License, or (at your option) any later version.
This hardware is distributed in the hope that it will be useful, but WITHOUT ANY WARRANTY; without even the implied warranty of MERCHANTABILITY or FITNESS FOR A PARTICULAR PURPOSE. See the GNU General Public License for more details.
